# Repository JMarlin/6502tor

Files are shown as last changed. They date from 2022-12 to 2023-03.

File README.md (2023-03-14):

# 6502tor

This is the project page for the 6502tor project, a minimal educational computer designed to teach the fundamentals of how a computer actually operates near the lowest levels.

If you received an assembled rev1 board as a holiday gift, it probably looks something like this:

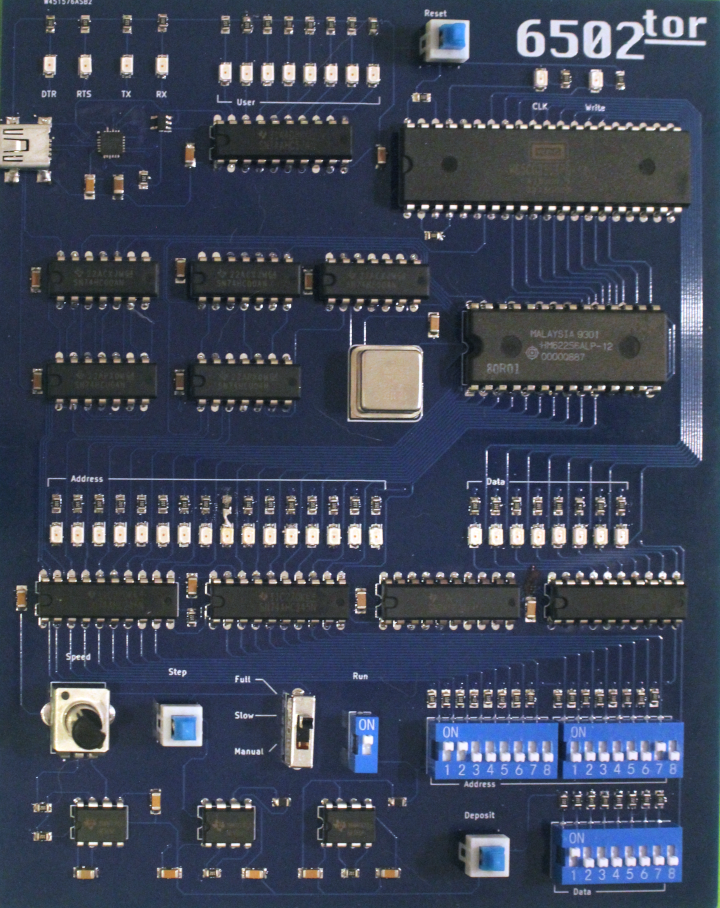
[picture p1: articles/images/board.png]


If you're interested in details about how the actual board is designed and built, you should check out the [hardware](hardware/README.md) section.

## Using The Hardware

This computer system is simultaneously incredibly simple while, by the token of complete open-endedness this implies, very complicated. With only a handful of controls, you can get the 6502tor to perform any function that can be done by *any other* computer.

For that reason, most of the system operation is going to be provided by a series of tutorial articles that will be published over time and which can be found below:

### Tutorials:
 - [0000 0001 - Overview and writing to memory](https://youtu.be/rqbeiZjz4c4)
 - [0000 0010 - Memory maps and binary](https://youtu.be/jSdUKUccR5Q)
 - [0000 0011 - Reset vector](https://youtu.be/KTeOp61t6co)
 - [0000 0100 - Executing your first instruction](https://youtu.be/9eZ2-8ygBwk)
 - [0000 0101 - Basic I/O](https://youtu.be/15wBBccO2ps)

### System Overview:

For the purpose of providing a quick reference so that you don't have to read through the articles if you need a reminder, the below chart provides a description of all the basic controls on the board:

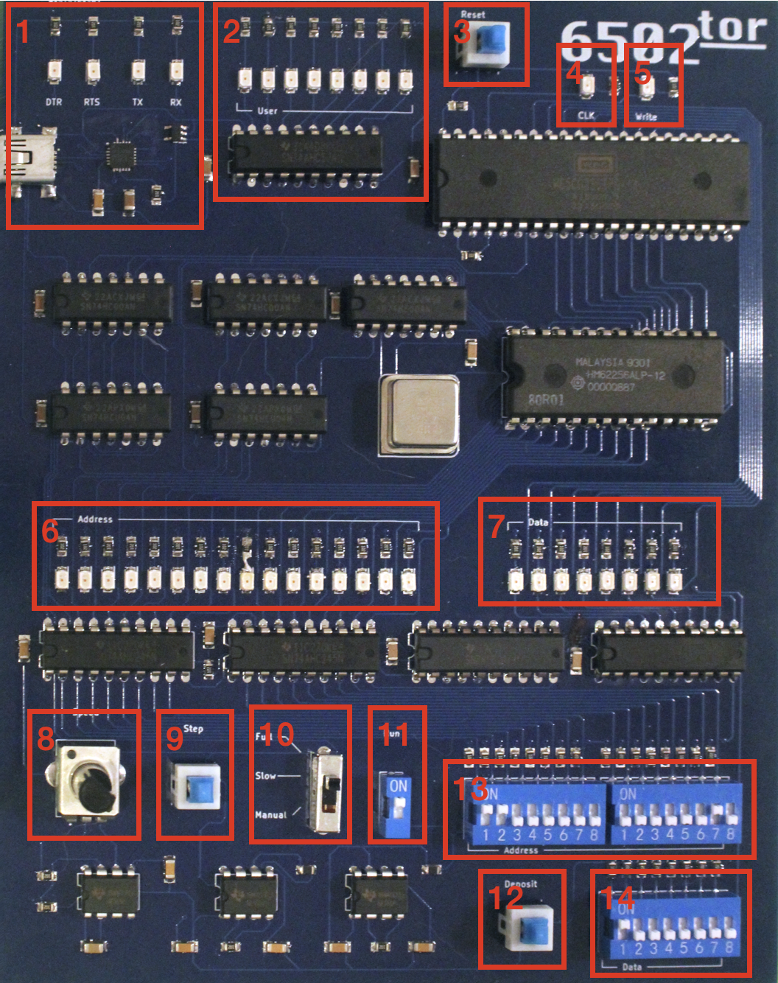
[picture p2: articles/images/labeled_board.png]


1. **USB Port** - Provides power to the system and also, in more advanced uses, serial communication with a host machine

2. **User Register** - Provides 8 bits of output and can be written to at any address between `0x4000` and `0xBFFF`. The top two bits are also attached to the USB chip for more advanced serial I/O purposes:
   - Bit 6: RXD
   - Bit 7: CTS

3. **CPU Reset** - A toggle switch that causes the CPU to do an internal reset when pressed in and allows the CPU to begin executing from the reset vector stored in RAM at `0xFFFC` when released. 
Should be pressed in for at least 3 clock cycles whenever the clock source is changed or in any other scenario where you want the CPU to begin running from its default state.

4. **CLK LED** - Displays the clock signal being fed into the CPU.

5. **Write LED** - Displays whether the system is currently reading or writing data from/to the bus. Probably backwards from what you expect, *there is a write occurring when this LED is **OFF***

6. **Address LEDs** - Display the address that is currently being driven on the address bus, whether that's by the CPU or by the `address switches` (depending on the run/program mode)

7. **Data LEDs** - Display the data that is currently being driven on the data bus, whether that's by the CPU or by the `data switches` (depending on the run/program mode). Note that in run mode, the data bus is only driven during the *high* portion of the clock cycle.

8. **Slow Clock Speed Control** - When the clock source switch is set to 'slow', controls the speed of the slow CPU clock (clockwise is faster).

9. **Step Button** - When the clock source switch is set to 'manual', directly controls the CPU clock. When pressed in, sets the `CLK` signal to low and when not pressed in sets the `CLK` signal to high.
It should be noted that data only appears on the data bus during the high portion of the clock cycle.

10. **Clock Source Switch** - Switches the CPU between three different clock sources/speed ranges:

     - **Full** - Connects the CPU directly to the 5 megahertz crystal oscillator (the metal can in the middle of the board)

     - **Slow** - Connects the CPU to a much slower RC oscillator that can run the CPU between ~0.5 hertz and a few kilohertz depending on how the `Slow Clock Speed Control` is set

     - **Manual** - Connects the clock directly to a debounced pushbutton so that you can manually step through clock cycles as slowly as you would like

11. **Run/Program Switch** - Switches the board between `run` mode, in which the CPU is controlling everything, and the `program` mode in which the CPU is disconnected from the bus and the data switches, address switches, and deposit button can be used to manually place instructions and data into RAM.

12. **Deposit Button** - When the run/program switch is in program mode, depressing this button causes the value set on the data switches to be written to the location specified by the address switches. *This is a toggle button, so make sure to press it twice for each deposit*.

13. **Address Switches** - When the run/program switch is in program mode, the value of these switches is displayed on the address LEDs and the value stored at that location is displayed on the data LEDs. If the deposit switch is pressed, the value on the data switches is written to the address set on these switches.

14. **Data Switches** - When the run/program switch is in program mode, the value on these switches is written to the location set on the address switches. When the run/program switch is in the run mode, the value of the lowest five data switches can be read at addresses from `0x4000` to `0x8FFF`. In this mode, the top three bits connect to the USB chip as follows:

    - Bit 5: TXD
    - Bit 6: RTS
    - Bit 7: DTR 

### Memory Map:
| **Start** | **End** | **Description** |
|---|---|---|
| 0x0000 | 0x3FFF  | 32K of RAM |
| 0x4000 | 0xBFFF  | Read data switches / Write user register |
| 0xC000 | 0xFFFF  | 32K of RAM |

## Reference Material And Resources
 - [6502 CPU datasheet](https://www.westerndesigncenter.com/wdc/documentation/w65c02s.pdf)
 - [6502 CPU instruction reference](https://www.masswerk.at/6502/6502_instruction_set.html)
 - [Online 6502 assembler](https://www.masswerk.at/6502/assembler.html) (for simple manual programming)
 - [cc65 compiler/cc65 assembler](https://github.com/cc65/cc65) (for more involved programming)
 - [RS232 serial communications on wikipedia](https://en.wikipedia.org/wiki/RS-232#Physical_interface)

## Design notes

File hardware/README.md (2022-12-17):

# Hardware

This directory contains the schematic and PCB project for the 6502tor hardware. The 6502tor board was designed in KiCAD, an EDA package that is free and open source. If you want to play with the CAD project, you can download KiCAD here:

 - [KiCAD Project Website](https://www.kicad.org/download/)

You can find the project in the `kicad` directory, but if you simply want to view the schematic you can find it in [the PDF in the same directory as this readme](6502tor_schematic.pdf)

## Caveats/Errata

Note that what is included here is the raw version of the project that was used to generate the first revision boards as shipped, and as such both include a handful of errors that are corrected on the shipped hardware with bodge wires:

 - Somehow KiCAD did not indicate to me that I managed to build two separate, unconnected ground nets. This can be fixed by making a connection between the ground pin (pin 10) on the user register IC (the 74574 next to the USB port) and the ground pin (pin 7) of any of the 7400 or 7404 chips in the glue logic section immediately below.

 - The order of the wires connecting the 74244 outputs back to the top three bits of the 74245 data tranceiver is reversed in the design from what it should be. This can be fixed by cutting the three traces that run just above the SMD capacitor located immediately to the left of the right-most 74245 (just above the DIP switches) and then connecting pins 2, 3, and 4 of that IC to pins 12, 14, and 16 of the adjacent 74244.

 - Bizarrely, there's absolutely no connection between the address bit 7 LED and its current-limiting resistor. The fix for this is to connect them.

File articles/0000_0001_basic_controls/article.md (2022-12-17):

-- **WIP** --
The basic system consists of a 6502 CPU, a 32-kilobyte RAM, an 8-bit 'user register' for output, and a set of toggle switches and buttons that are used to load code and data into memory, switch between data entry/run mode, and control the CPU execution speed.

This is modeled off of 'full size' computers (as opposed to microcomputers) of the 50s through 70s -- back when there weren't any very good ROM technologies and the machine would be bootstrapped by loading initial code into RAM via one of these 'blinkenlights front panels' -- for more info on their history, check out [this wiki article](https://en.wikipedia.org/wiki/Front_panel). 

The 6502tor is built around a 6502 CPU, a type of 8-bit CPU that's been in production since 1975 and was used in a number of notable machines throughout the 80s including the Apple II, Commodore 64, BBC Micro, and even the Nintendo Entertainment System and Atari 2600.

A CPU communicates with the outside world by loading and storing commands and data between other devices that are connected to it. This loading and storing is done using a pair of busses called the `address bus` and the `data bus` along with a set of `control signals` ('bus' is just a fancy word for a bunch of related wires). The address bus tells connected devices *where* data should be read or written from/to, the data bus carries the actual data itself, and finally the control signals tell the connected devices *when and how* to perform the transfer.

Devices that connect to the CPU

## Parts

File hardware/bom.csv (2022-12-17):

Source: | /Users/josephmarlin/Documents/KiCad/6.0/projects/6502tor/6502tor.kicad_sch
Date: | Wednesday, December 07, 2022 at 05:16:50 PM
Tool: | Eeschema (6.0.9-0)
Generator: | /Applications/KiCad/KiCad.app/Contents/SharedSupport/plugins/bom_csv_grouped_by_value.py
Component Count: | 158
Individual Components:
Item | Qty | Reference(s) | Value | LibPart | Footprint | Datasheet
 |  | C1 | 0.01uf | 6502tor-eagle-import:C-USC1206 | 6502tor:C1206
 |  | C2 | 1uf | 6502tor-eagle-import:C-USC1206 | 6502tor:C1206
 |  | C3 | 0.01uf | 6502tor-eagle-import:C-USC1206 | 6502tor:C1206
 |  | C4 | 0.1uf | 6502tor-eagle-import:C-USC1206 | 6502tor:C1206
 |  | C5 | 0.1uf | 6502tor-eagle-import:C-USC1206 | 6502tor:C1206
 |  | C6 | 0.01uf | 6502tor-eagle-import:C-USC1206 | 6502tor:C1206
 |  | C7 | 0.1uf | 6502tor-eagle-import:C-USC1206 | 6502tor:C1206
 |  | C8 | 4.7uf | 6502tor-eagle-import:C-USC1206 | 6502tor:C1206
 |  | C9 | 0.1uf | 6502tor-eagle-import:C-USC1206 | 6502tor:C1206
 |  | C10 | 0.1uf | 6502tor-eagle-import:C-USC1206 | 6502tor:C1206
 |  | C11 | 0.1uf | 6502tor-eagle-import:C-USC1206 | 6502tor:C1206
 |  | C12 | 0.1uf | 6502tor-eagle-import:C-USC1206 | 6502tor:C1206
 |  | C13 | 0.1uf | 6502tor-eagle-import:C-USC1206 | 6502tor:C1206
 |  | C14 | 0.1uf | 6502tor-eagle-import:C-USC1206 | 6502tor:C1206
 |  | C15 | 0.1uf | 6502tor-eagle-import:C-USC1206 | 6502tor:C1206
 |  | C16 | 0.1uf | 6502tor-eagle-import:C-USC1206 | 6502tor:C1206
 |  | C17 | 0.1uf | 6502tor-eagle-import:C-USC1206 | 6502tor:C1206
 |  | C18 | 0.1uf | 6502tor-eagle-import:C-USC1206 | 6502tor:C1206
 |  | C19 | 0.1uf | 6502tor-eagle-import:C-USC1206 | 6502tor:C1206
 |  | C20 | 0.1uf | 6502tor-eagle-import:C-USC1206 | 6502tor:C1206
 |  | IC1 | W65C02SP | 6502tor-eagle-import:W65C02SP | 6502tor:DIL40
 |  | IC2 | 74245N | 6502tor-eagle-import:74245N | 6502tor:DIL20
 |  | IC3 | 7400N | 6502tor-eagle-import:7400N | 6502tor:DIL14
 |  | IC4 | 7400N | 6502tor-eagle-import:7400N | 6502tor:DIL14
 |  | IC5 | 7400N | 6502tor-eagle-import:7400N | 6502tor:DIL14
 |  | IC6 | 555N | 6502tor-eagle-import:555N | 6502tor:DIL08
 |  | IC7 | 555N | 6502tor-eagle-import:555N | 6502tor:DIL08
 |  | IC8 | 7404N | 6502tor-eagle-import:7404N | 6502tor:DIL14
 |  | IC9 | 7404N | 6502tor-eagle-import:7404N | 6502tor:DIL14
 |  | IC10 | 555N | 6502tor-eagle-import:555N | 6502tor:DIL08
 |  | IC11 | 74245N | 6502tor-eagle-import:74245N | 6502tor:DIL20
 |  | IC12 | 74245N | 6502tor-eagle-import:74245N | 6502tor:DIL20
 |  | IC14 | 74244N | 6502tor-eagle-import:74244N | 6502tor:DIL20
 |  | IC15 | 74574N | 6502tor-eagle-import:74574N | 6502tor:DIL20
 |  | IC16 | CP2102N-A02-GQFN24 | 6502tor-eagle-import:CP2102N-A02-GQFN24 | 6502tor:QFN50P400X400X80-25N
 |  | IC17 | TPS7A2036PDBVR | 6502tor-eagle-import:TPS7A2036PDBVR | 6502tor:SOT95P280X145-5N
 |  | J1 | UJ2-MBH-1-SMT-TR | 6502tor-eagle-import:UJ2-MBH-1-SMT-TR | 6502tor:UJ2MBH1SMTTR
 |  | LED1 | CLM3C-AKW-CTBVA253 | 6502tor-eagle-import:CLM3C-AKW-CTBVA253 | 6502tor:LEDM3020X140N
 |  | LED2 | CLM3C-AKW-CTBVA253 | 6502tor-eagle-import:CLM3C-AKW-CTBVA253 | 6502tor:LEDM3020X140N
 |  | LED3 | CLM3C-AKW-CTBVA253 | 6502tor-eagle-import:CLM3C-AKW-CTBVA253 | 6502tor:LEDM3020X140N
 |  | LED4 | CLM3C-AKW-CTBVA253 | 6502tor-eagle-import:CLM3C-AKW-CTBVA253 | 6502tor:LEDM3020X140N
 |  | LED5 | CLM3C-AKW-CTBVA253 | 6502tor-eagle-import:CLM3C-AKW-CTBVA253 | 6502tor:LEDM3020X140N
 |  | LED6 | CLM3C-AKW-CTBVA253 | 6502tor-eagle-import:CLM3C-AKW-CTBVA253 | 6502tor:LEDM3020X140N
 |  | LED7 | CLM3C-AKW-CTBVA253 | 6502tor-eagle-import:CLM3C-AKW-CTBVA253 | 6502tor:LEDM3020X140N
 |  | LED8 | CLM3C-AKW-CTBVA253 | 6502tor-eagle-import:CLM3C-AKW-CTBVA253 | 6502tor:LEDM3020X140N
 |  | LED9 | CLM3C-AKW-CTBVA253 | 6502tor-eagle-import:CLM3C-AKW-CTBVA253 | 6502tor:LEDM3020X140N
 |  | LED10 | CLM3C-AKW-CTBVA253 | 6502tor-eagle-import:CLM3C-AKW-CTBVA253 | 6502tor:LEDM3020X140N
 |  | LED11 | CLM3C-AKW-CTBVA253 | 6502tor-eagle-import:CLM3C-AKW-CTBVA253 | 6502tor:LEDM3020X140N
 |  | LED12 | CLM3C-AKW-CTBVA253 | 6502tor-eagle-import:CLM3C-AKW-CTBVA253 | 6502tor:LEDM3020X140N
 |  | LED13 | CLM3C-AKW-CTBVA253 | 6502tor-eagle-import:CLM3C-AKW-CTBVA253 | 6502tor:LEDM3020X140N
 |  | LED14 | CLM3C-AKW-CTBVA253 | 6502tor-eagle-import:CLM3C-AKW-CTBVA253 | 6502tor:LEDM3020X140N
 |  | LED15 | CLM3C-AKW-CTBVA253 | 6502tor-eagle-import:CLM3C-AKW-CTBVA253 | 6502tor:LEDM3020X140N
 |  | LED16 | CLM3C-AKW-CTBVA253 | 6502tor-eagle-import:CLM3C-AKW-CTBVA253 | 6502tor:LEDM3020X140N
 |  | LED17 | CLM3C-AKW-CTBVA253 | 6502tor-eagle-import:CLM3C-AKW-CTBVA253 | 6502tor:LEDM3020X140N
 |  | LED18 | CLM3C-AKW-CTBVA253 | 6502tor-eagle-import:CLM3C-AKW-CTBVA253 | 6502tor:LEDM3020X140N
 |  | LED19 | CLM3C-AKW-CTBVA253 | 6502tor-eagle-import:CLM3C-AKW-CTBVA253 | 6502tor:LEDM3020X140N
 |  | LED20 | CLM3C-AKW-CTBVA253 | 6502tor-eagle-import:CLM3C-AKW-CTBVA253 | 6502tor:LEDM3020X140N
 |  | LED21 | CLM3C-AKW-CTBVA253 | 6502tor-eagle-import:CLM3C-AKW-CTBVA253 | 6502tor:LEDM3020X140N
 |  | LED22 | CLM3C-AKW-CTBVA253 | 6502tor-eagle-import:CLM3C-AKW-CTBVA253 | 6502tor:LEDM3020X140N
 |  | LED23 | CLM3C-AKW-CTBVA253 | 6502tor-eagle-import:CLM3C-AKW-CTBVA253 | 6502tor:LEDM3020X140N
 |  | LED24 | CLM3C-AKW-CTBVA253 | 6502tor-eagle-import:CLM3C-AKW-CTBVA253 | 6502tor:LEDM3020X140N
 |  | LED25 | CLM3C-AKW-CTBVA253 | 6502tor-eagle-import:CLM3C-AKW-CTBVA253 | 6502tor:LEDM3020X140N
 |  | LED26 | CLM3C-AKW-CTBVA253 | 6502tor-eagle-import:CLM3C-AKW-CTBVA253 | 6502tor:LEDM3020X140N
 |  | LED27 | CLM3C-AKW-CTBVA253 | 6502tor-eagle-import:CLM3C-AKW-CTBVA253 | 6502tor:LEDM3020X140N
 |  | LED28 | CLM3C-AKW-CTBVA253 | 6502tor-eagle-import:CLM3C-AKW-CTBVA253 | 6502tor:LEDM3020X140N
 |  | LED29 | CLM3C-AKW-CTBVA253 | 6502tor-eagle-import:CLM3C-AKW-CTBVA253 | 6502tor:LEDM3020X140N
 |  | LED30 | CLM3C-AKW-CTBVA253 | 6502tor-eagle-import:CLM3C-AKW-CTBVA253 | 6502tor:LEDM3020X140N
 |  | LED31 | CLM3C-AKW-CTBVA253 | 6502tor-eagle-import:CLM3C-AKW-CTBVA253 | 6502tor:LEDM3020X140N
 |  | LED32 | CLM3C-AKW-CTBVA253 | 6502tor-eagle-import:CLM3C-AKW-CTBVA253 | 6502tor:LEDM3020X140N
 |  | LED33 | CLM3C-AKW-CTBVA253 | 6502tor-eagle-import:CLM3C-AKW-CTBVA253 | 6502tor:LEDM3020X140N
 |  | LED34 | CLM3C-AKW-CTBVA253 | 6502tor-eagle-import:CLM3C-AKW-CTBVA253 | 6502tor:LEDM3020X140N
 |  | LED35 | CLM3C-AKW-CTBVA253 | 6502tor-eagle-import:CLM3C-AKW-CTBVA253 | 6502tor:LEDM3020X140N
 |  | LED36 | CLM3C-AKW-CTBVA253 | 6502tor-eagle-import:CLM3C-AKW-CTBVA253 | 6502tor:LEDM3020X140N
 |  | LED37 | CLM3C-AKW-CTBVA253 | 6502tor-eagle-import:CLM3C-AKW-CTBVA253 | 6502tor:LEDM3020X140N
 |  | LED38 | CLM3C-AKW-CTBVA253 | 6502tor-eagle-import:CLM3C-AKW-CTBVA253 | 6502tor:LEDM3020X140N
 |  | QG1 | QG5460 | 6502tor-eagle-import:QG5460 | 6502tor:DIL08S
 |  | R1 | R-US_R0805 | 6502tor-eagle-import:R-US_R0805 | 6502tor:R0805
 |  | R2 | R-US_R0805 | 6502tor-eagle-import:R-US_R0805 | 6502tor:R0805
 |  | R3 | R-US_R0805 | 6502tor-eagle-import:R-US_R0805 | 6502tor:R0805
 |  | R4 | R-US_R0805 | 6502tor-eagle-import:R-US_R0805 | 6502tor:R0805
 |  | R5 | R-US_R0805 | 6502tor-eagle-import:R-US_R0805 | 6502tor:R0805
 |  | R6 | R-US_R0805 | 6502tor-eagle-import:R-US_R0805 | 6502tor:R0805
 |  | R7 | R-US_R0805 | 6502tor-eagle-import:R-US_R0805 | 6502tor:R0805
 |  | R8 | R-US_R0805 | 6502tor-eagle-import:R-US_R0805 | 6502tor:R0805
 |  | R9 | R-US_R0805 | 6502tor-eagle-import:R-US_R0805 | 6502tor:R0805
 |  | R10 | R-US_R0805 | 6502tor-eagle-import:R-US_R0805 | 6502tor:R0805
 |  | R11 | R-US_R0805 | 6502tor-eagle-import:R-US_R0805 | 6502tor:R0805
 |  | R12 | R-US_R0805 | 6502tor-eagle-import:R-US_R0805 | 6502tor:R0805
 |  | R13 | R-US_R0805 | 6502tor-eagle-import:R-US_R0805 | 6502tor:R0805
 |  | R14 | R-US_R0805 | 6502tor-eagle-import:R-US_R0805 | 6502tor:R0805
 |  | R15 | R-US_R0805 | 6502tor-eagle-import:R-US_R0805 | 6502tor:R0805
 |  | R16 | R-US_R0805 | 6502tor-eagle-import:R-US_R0805 | 6502tor:R0805
 |  | R17 | R-US_R0805 | 6502tor-eagle-import:R-US_R0805 | 6502tor:R0805
 |  | R18 | R-US_R0805 | 6502tor-eagle-import:R-US_R0805 | 6502tor:R0805
 |  | R19 | R-US_R0805 | 6502tor-eagle-import:R-US_R0805 | 6502tor:R0805
 |  | R20 | R-US_R0805 | 6502tor-eagle-import:R-US_R0805 | 6502tor:R0805
 |  | R21 | R-US_R0805 | 6502tor-eagle-import:R-US_R0805 | 6502tor:R0805
 |  | R22 | R-US_R0805 | 6502tor-eagle-import:R-US_R0805 | 6502tor:R0805
 |  | R23 | R-US_R0805 | 6502tor-eagle-import:R-US_R0805 | 6502tor:R0805
 |  | R24 | R-US_R0805 | 6502tor-eagle-import:R-US_R0805 | 6502tor:R0805
 |  | R25 | R-US_R0805 | 6502tor-eagle-import:R-US_R0805 | 6502tor:R0805
 |  | R26 | R-US_R0805 | 6502tor-eagle-import:R-US_R0805 | 6502tor:R0805
 |  | R27 | R-US_R0805 | 6502tor-eagle-import:R-US_R0805 | 6502tor:R0805
 |  | R28 | R-US_R0805 | 6502tor-eagle-import:R-US_R0805 | 6502tor:R0805
 |  | R29 | R-US_R0805 | 6502tor-eagle-import:R-US_R0805 | 6502tor:R0805
 |  | R30 | R-US_R0805 | 6502tor-eagle-import:R-US_R0805 | 6502tor:R0805
 |  | R31 | R-US_R0805 | 6502tor-eagle-import:R-US_R0805 | 6502tor:R0805
 |  | R32 | R-US_R0805 | 6502tor-eagle-import:R-US_R0805 | 6502tor:R0805
 |  | R33 | R-US_R0805 | 6502tor-eagle-import:R-US_R0805 | 6502tor:R0805
 |  | R34 | R-US_R0805 | 6502tor-eagle-import:R-US_R0805 | 6502tor:R0805
 |  | R35 | R-US_R0805 | 6502tor-eagle-import:R-US_R0805 | 6502tor:R0805
 |  | R36 | R-US_R0805 | 6502tor-eagle-import:R-US_R0805 | 6502tor:R0805
 |  | R37 | R-US_R0805 | 6502tor-eagle-import:R-US_R0805 | 6502tor:R0805
 |  | R38 | R-US_R0805 | 6502tor-eagle-import:R-US_R0805 | 6502tor:R0805
 |  | R39 | R-US_R0805 | 6502tor-eagle-import:R-US_R0805 | 6502tor:R0805
 |  | R40 | R-US_R0805 | 6502tor-eagle-import:R-US_R0805 | 6502tor:R0805
 |  | R41 | R-US_R0805 | 6502tor-eagle-import:R-US_R0805 | 6502tor:R0805
 |  | R42 | R-US_R0805 | 6502tor-eagle-import:R-US_R0805 | 6502tor:R0805
 |  | R43 | R-US_R0805 | 6502tor-eagle-import:R-US_R0805 | 6502tor:R0805
 |  | R44 | R-US_R0805 | 6502tor-eagle-import:R-US_R0805 | 6502tor:R0805
 |  | R45 | R-US_R0805 | 6502tor-eagle-import:R-US_R0805 | 6502tor:R0805
 |  | R46 | R-US_R0805 | 6502tor-eagle-import:R-US_R0805 | 6502tor:R0805
 |  | R47 | R-US_R0805 | 6502tor-eagle-import:R-US_R0805 | 6502tor:R0805
 |  | R48 | R-US_R0805 | 6502tor-eagle-import:R-US_R0805 | 6502tor:R0805
 |  | R49 | R-US_R0805 | 6502tor-eagle-import:R-US_R0805 | 6502tor:R0805
 |  | R50 | R-US_R0805 | 6502tor-eagle-import:R-US_R0805 | 6502tor:R0805
 |  | R51 | R-US_R0805 | 6502tor-eagle-import:R-US_R0805 | 6502tor:R0805
 |  | R52 | R-US_R0805 | 6502tor-eagle-import:R-US_R0805 | 6502tor:R0805
 |  | R53 | R-US_R0805 | 6502tor-eagle-import:R-US_R0805 | 6502tor:R0805
 |  | R54 | R-US_R0805 | 6502tor-eagle-import:R-US_R0805 | 6502tor:R0805
 |  | R55 | R-US_R0805 | 6502tor-eagle-import:R-US_R0805 | 6502tor:R0805
 |  | R56 | R-US_R0805 | 6502tor-eagle-import:R-US_R0805 | 6502tor:R0805
 |  | R57 | R-US_R0805 | 6502tor-eagle-import:R-US_R0805 | 6502tor:R0805
 |  | R58 | R-US_R0805 | 6502tor-eagle-import:R-US_R0805 | 6502tor:R0805
 |  | R59 | R-US_R0805 | 6502tor-eagle-import:R-US_R0805 | 6502tor:R0805
 |  | R60 | PTV09A-4020F-B105 | 6502tor-eagle-import:PTV09A-4020F-B105 | 6502tor:PTV09A4020FB103
 |  | R61 | 1K | 6502tor-eagle-import:R-US_R0805 | 6502tor:R0805
 |  | R62 | 1K | 6502tor-eagle-import:R-US_R0805 | 6502tor:R0805
 |  | R63 | 1K | 6502tor-eagle-import:R-US_R0805 | 6502tor:R0805
 |  | R64 | 1M | 6502tor-eagle-import:R-US_R0805 | 6502tor:R0805
 |  | R65 | 1K | 6502tor-eagle-import:R-US_R0805 | 6502tor:R0805
 |  | R66 | 1M | 6502tor-eagle-import:R-US_R0805 | 6502tor:R0805
 |  | R67 | 1K | 6502tor-eagle-import:R-US_R0805 | 6502tor:R0805
 |  | R68 | R-US_R0805 | 6502tor-eagle-import:R-US_R0805 | 6502tor:R0805
 |  | R69 | R-US_R0805 | 6502tor-eagle-import:R-US_R0805 | 6502tor:R0805
 |  | R70 | 1K | 6502tor-eagle-import:R-US_R0805 | 6502tor:R0805
 |  | R71 | 1K | 6502tor-eagle-import:R-US_R0805 | 6502tor:R0805
 |  | R72 | 1K | 6502tor-eagle-import:R-US_R0805 | 6502tor:R0805
 |  | R73 | 1K | 6502tor-eagle-import:R-US_R0805 | 6502tor:R0805
 |  | S1 | MHPS2273 | 6502tor-eagle-import:MHPS2273 | 6502tor:MHPS2273
 |  | S3 | MHPS2273 | 6502tor-eagle-import:MHPS2273 | 6502tor:MHPS2273
 |  | S4 | OS103011MS8QP1 | 6502tor-eagle-import:OS103011MS8QP1 | 6502tor:OS103011MS8QP1
 |  | S5 | MHPS2273 | 6502tor-eagle-import:MHPS2273 | 6502tor:MHPS2273
 |  | SW1 | SW_DIP-8 | 6502tor-eagle-import:SW_DIP-8 | 6502tor:EDG-08
 |  | SW2 | SW_DIP-8 | 6502tor-eagle-import:SW_DIP-8 | 6502tor:EDG-08
 |  | SW3 | SW_DIP-8 | 6502tor-eagle-import:SW_DIP-8 | 6502tor:EDG-08
 |  | SW4 | SW_DIP-1 | 6502tor-eagle-import:SW_DIP-1 | 6502tor:EDG-01
 |  | U1 | HM62256BLP | Memory_RAM:HM62256BLP | Package_DIP:DIP-28_W15.24mm | https://web.mit.edu/6.115/www/document/62256.pdf
Collated Components:
Item | Qty | Reference(s) | Value | LibPart | Footprint | Datasheet
1 | 3 | C1, C3, C6 | 0.01uf | 6502tor-eagle-import:C-USC1206 | 6502tor:C1206
2 | 1 | C2 | 1uf | 6502tor-eagle-import:C-USC1206 | 6502tor:C1206
3 | 15 | C4, C5, C7, C9, C10, C11, C12, C13, C14, C15, C16, C17, C18, C19, C20 | 0.1uf | 6502tor-eagle-import:C-USC1206 | 6502tor:C1206
4 | 1 | C8 | 4.7uf | 6502tor-eagle-import:C-USC1206 | 6502tor:C1206
5 | 1 | IC1 | W65C02SP | 6502tor-eagle-import:W65C02SP | 6502tor:DIL40
6 | 3 | IC2, IC11, IC12 | 74245N | 6502tor-eagle-import:74245N | 6502tor:DIL20
7 | 3 | IC3, IC4, IC5 | 7400N | 6502tor-eagle-import:7400N | 6502tor:DIL14
8 | 3 | IC6, IC7, IC10 | 555N | 6502tor-eagle-import:555N | 6502tor:DIL08
9 | 2 | IC8, IC9 | 7404N | 6502tor-eagle-import:7404N | 6502tor:DIL14
10 | 1 | IC14 | 74244N | 6502tor-eagle-import:74244N | 6502tor:DIL20
11 | 1 | IC15 | 74574N | 6502tor-eagle-import:74574N | 6502tor:DIL20
12 | 1 | IC16 | CP2102N-A02-GQFN24 | 6502tor-eagle-import:CP2102N-A02-GQFN24 | 6502tor:QFN50P400X400X80-25N
13 | 1 | IC17 | TPS7A2036PDBVR | 6502tor-eagle-import:TPS7A2036PDBVR | 6502tor:SOT95P280X145-5N
14 | 1 | J1 | UJ2-MBH-1-SMT-TR | 6502tor-eagle-import:UJ2-MBH-1-SMT-TR | 6502tor:UJ2MBH1SMTTR
15 | 38 | LED1, LED2, LED3, LED4, LED5, LED6, LED7, LED8, LED9, LED10, LED11, LED12, LED13, LED14, LED15, LED16, LED17, LED18, LED19, LED20, LED21, LED22, LED23, LED24, LED25, LED26, LED27, LED28, LED29, LED30, LED31, LED32, LED33, LED34, LED35, LED36, LED37, LED38 | CLM3C-AKW-CTBVA253 | 6502tor-eagle-import:CLM3C-AKW-CTBVA253 | 6502tor:LEDM3020X140N
16 | 1 | QG1 | QG5460 | 6502tor-eagle-import:QG5460 | 6502tor:DIL08S
17 | 61 | R1, R2, R3, R4, R5, R6, R7, R8, R9, R10, R11, R12, R13, R14, R15, R16, R17, R18, R19, R20, R21, R22, R23, R24, R25, R26, R27, R28, R29, R30, R31, R32, R33, R34, R35, R36, R37, R38, R39, R40, R41, R42, R43, R44, R45, R46, R47, R48, R49, R50, R51, R52, R53, R54, R55, R56, R57, R58, R59, R68, R69 | R-US_R0805 | 6502tor-eagle-import:R-US_R0805 | 6502tor:R0805
18 | 1 | R60 | PTV09A-4020F-B105 | 6502tor-eagle-import:PTV09A-4020F-B105 | 6502tor:PTV09A4020FB103
19 | 9 | R61, R62, R63, R65, R67, R70, R71, R72, R73 | 1K | 6502tor-eagle-import:R-US_R0805 | 6502tor:R0805
20 | 2 | R64, R66 | 1M | 6502tor-eagle-import:R-US_R0805 | 6502tor:R0805
21 | 3 | S1, S3, S5 | MHPS2273 | 6502tor-eagle-import:MHPS2273 | 6502tor:MHPS2273
22 | 1 | S4 | OS103011MS8QP1 | 6502tor-eagle-import:OS103011MS8QP1 | 6502tor:OS103011MS8QP1
23 | 3 | SW1, SW2, SW3 | SW_DIP-8 | 6502tor-eagle-import:SW_DIP-8 | 6502tor:EDG-08
24 | 1 | SW4 | SW_DIP-1 | 6502tor-eagle-import:SW_DIP-1 | 6502tor:EDG-01
25 | 1 | U1 | HM62256BLP | Memory_RAM:HM62256BLP | Package_DIP:DIP-28_W15.24mm | https://web.mit.edu/6.115/www/document/62256.pdf

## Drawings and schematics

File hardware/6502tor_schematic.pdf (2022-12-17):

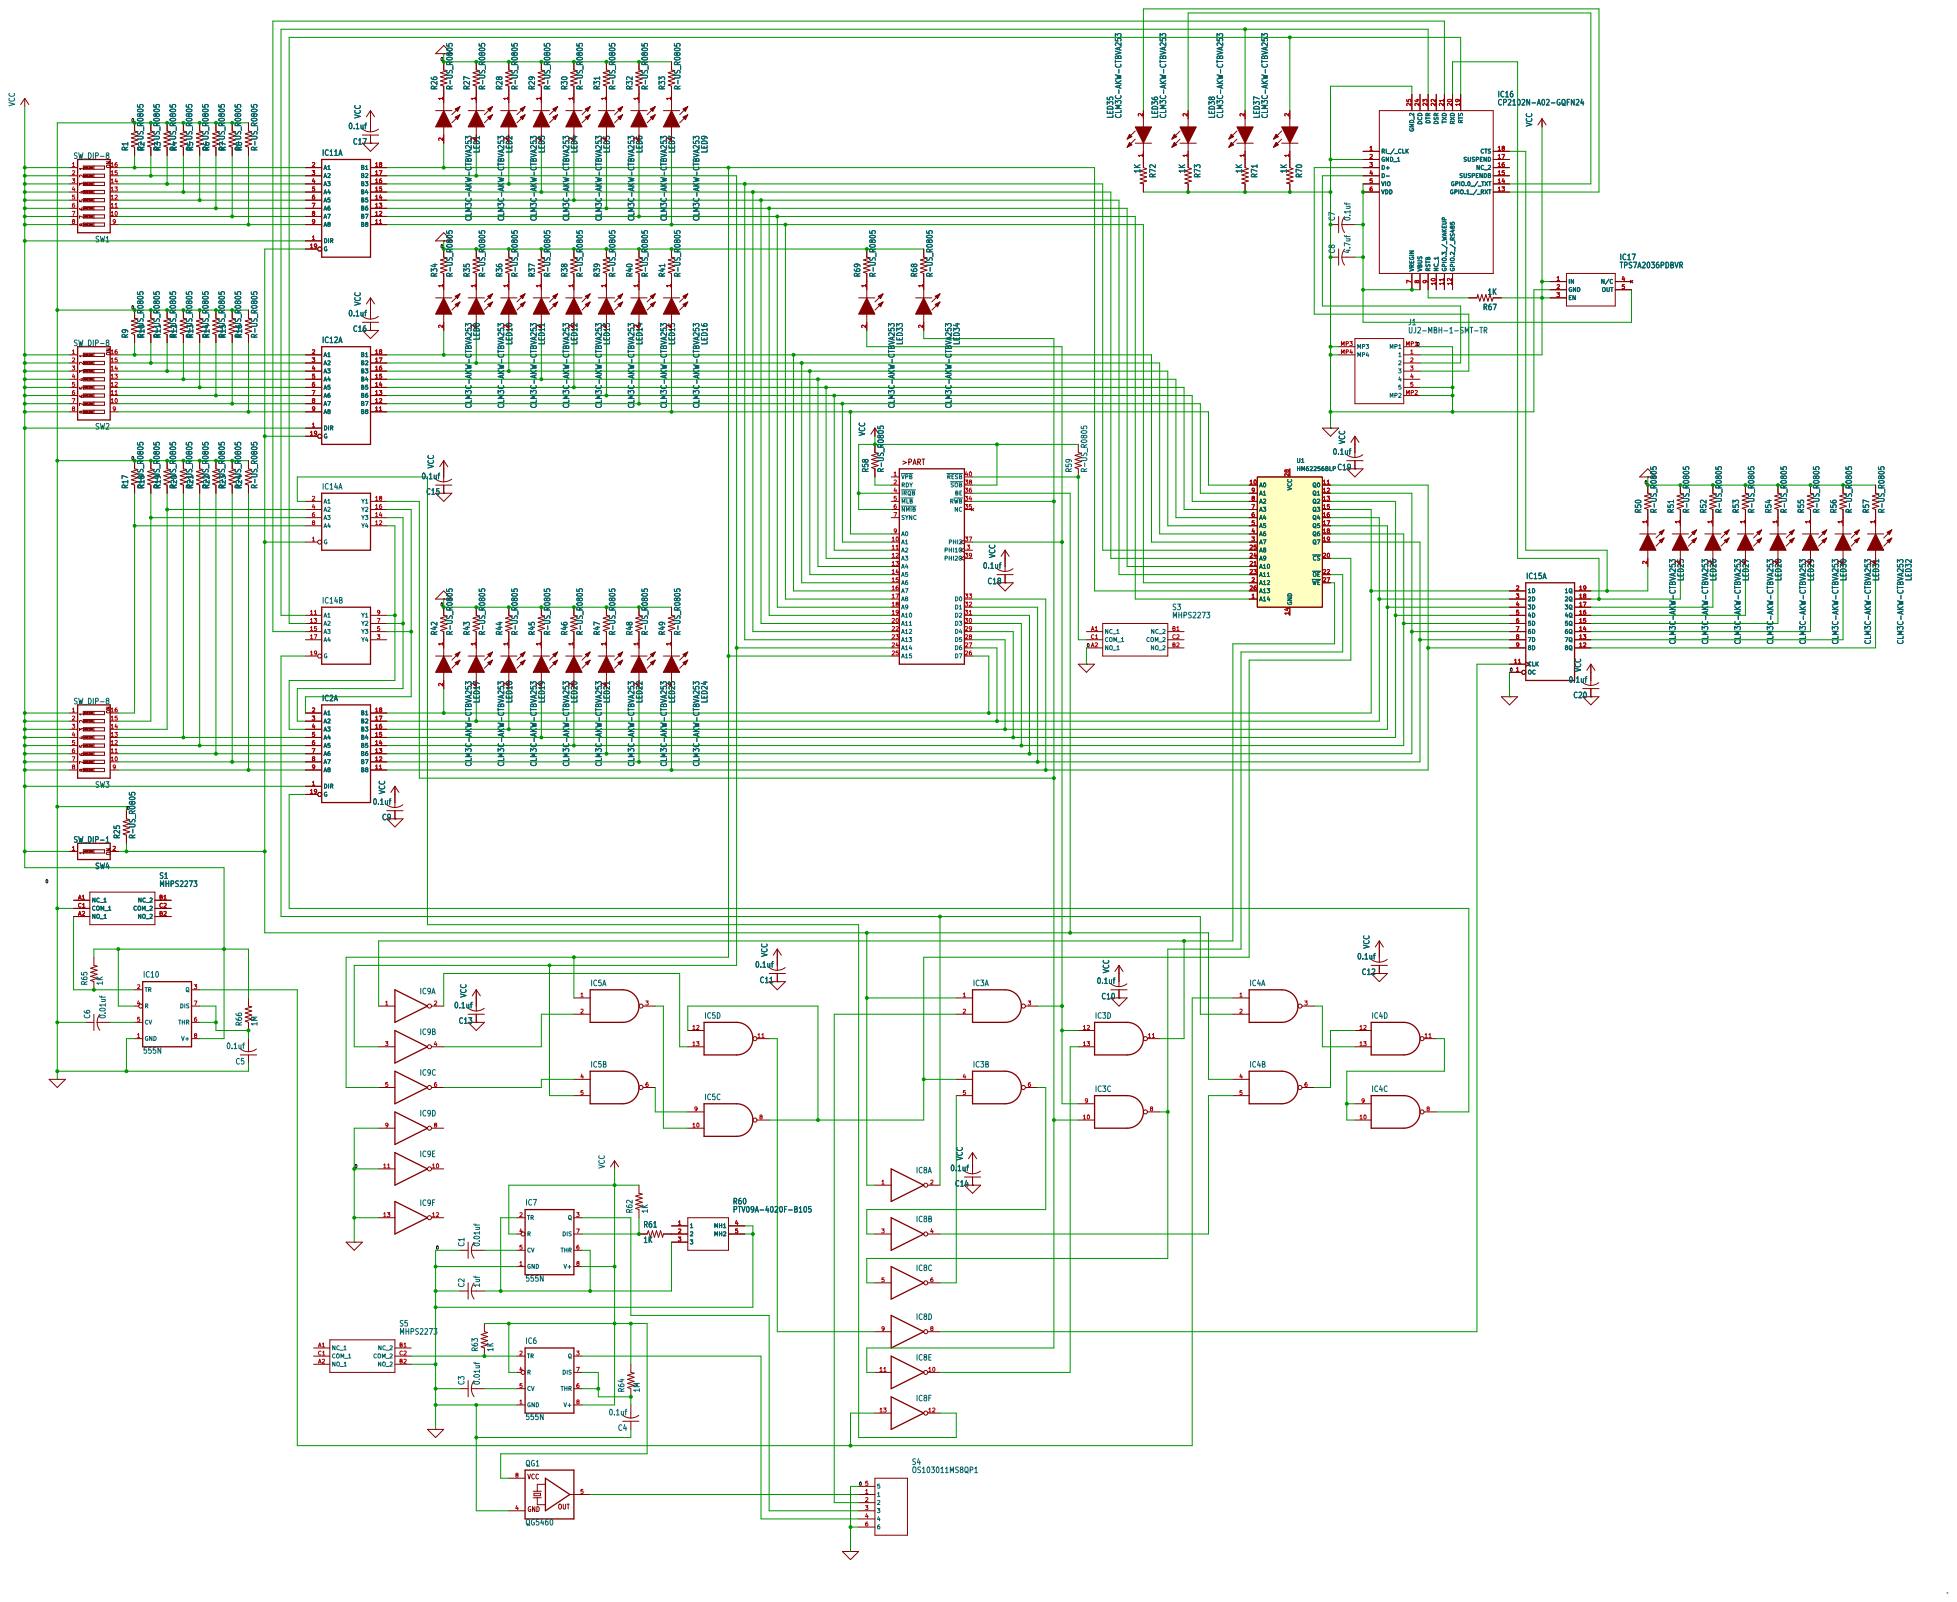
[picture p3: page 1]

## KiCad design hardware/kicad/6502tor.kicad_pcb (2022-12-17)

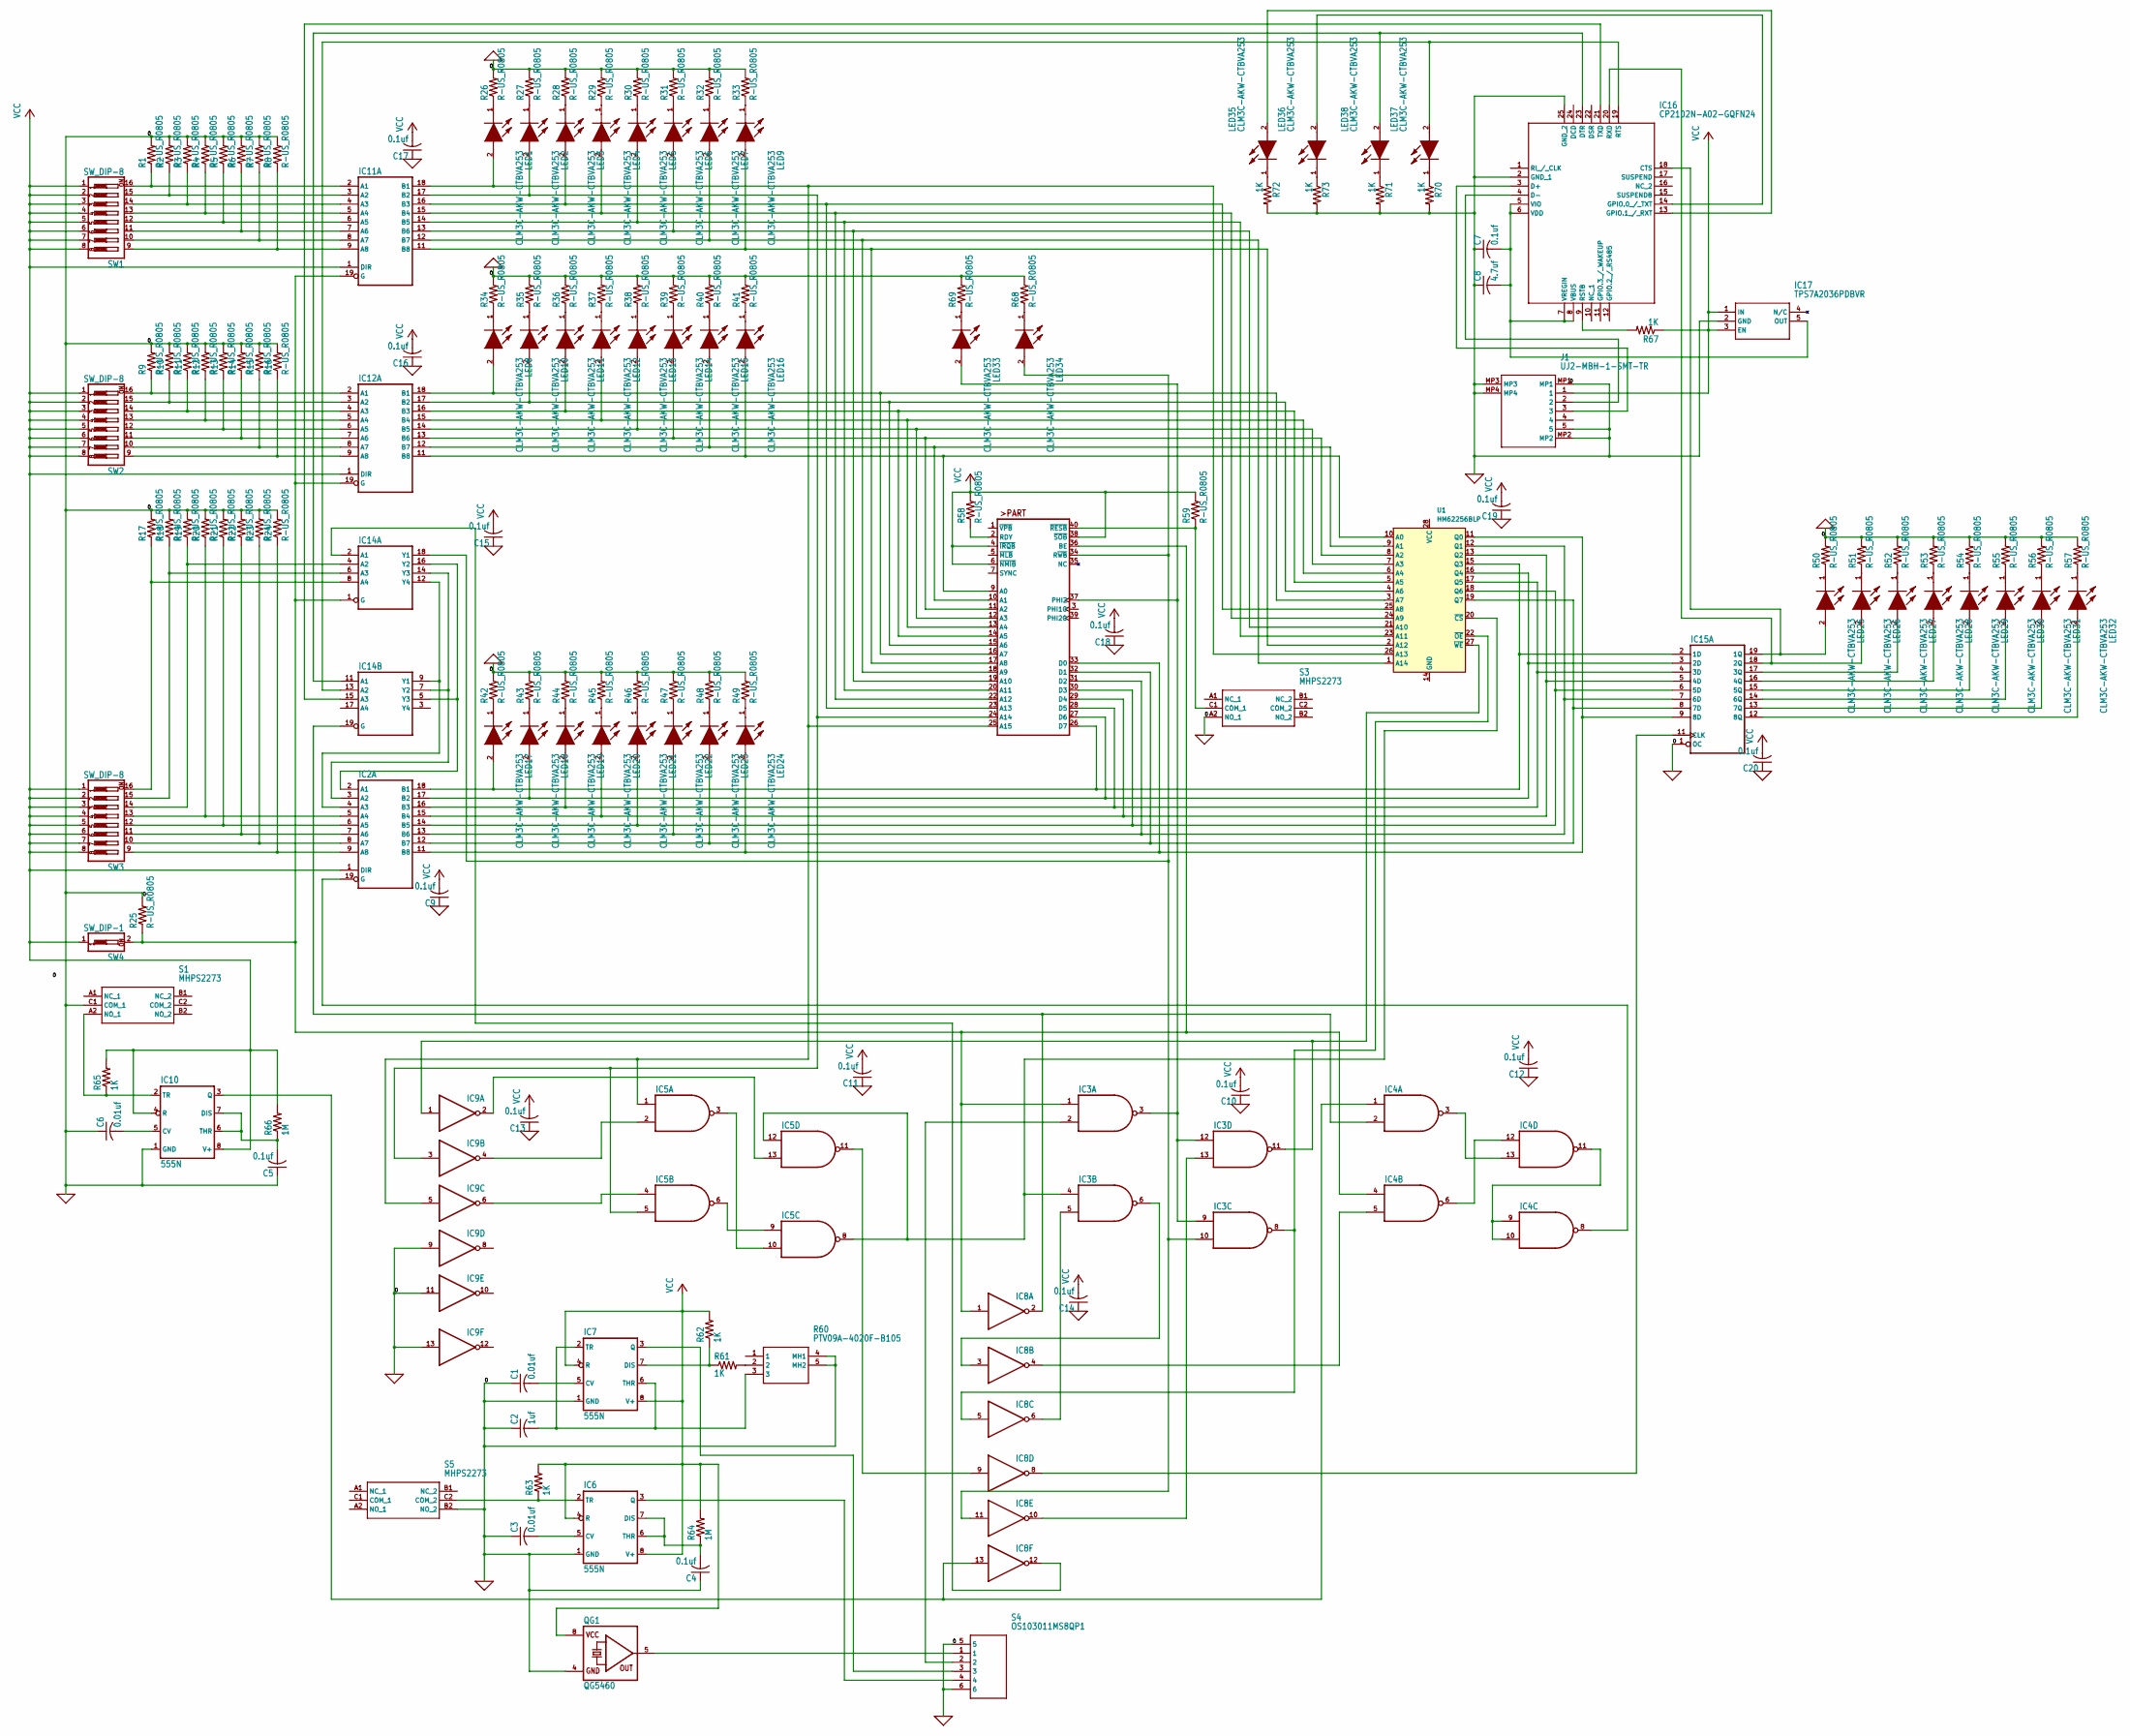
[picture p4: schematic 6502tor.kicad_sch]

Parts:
C1, C3, C6: 0.01uf; C1206
C2: 1uf; C1206
C4, C5, C7, C9, C10, C11, C12, C13, C14, C15, C16, C17, C18, C19, C20: 0.1uf; C1206
C8: 4.7uf; C1206
IC1: W65C02SP; DIL40
IC2, IC11, IC12: 74245N; DIL20
IC3, IC4, IC5: 7400N; DIL14
IC6, IC7, IC10: 555N; DIL08
IC8, IC9: 7404N; DIL14
IC14: 74244N; DIL20
IC15: 74574N; DIL20
IC16: CP2102N-A02-GQFN24; QFN50P400X400X80-25N
IC17: TPS7A2036PDBVR; SOT95P280X145-5N
J1: UJ2-MBH-1-SMT-TR; UJ2MBH1SMTTR
LED1, LED2, LED3, LED4, LED5, LED6, LED7, LED8, LED9, LED10, LED11, LED12, LED13, LED14, LED15, LED16, LED17, LED18, LED19, LED20, LED21, LED22, LED23, LED24, LED25, LED26, LED27, LED28, LED29, LED30, LED31, LED32, LED33, LED34, LED35, LED36, LED37, LED38: CLM3C-AKW-CTBVA253; LEDM3020X140N
QG1: QG5460; DIL08S
R1, R2, R3, R4, R5, R6, R7, R8, R9, R10, R11, R12, R13, R14, R15, R16, R17, R18, R19, R20, R21, R22, R23, R24, R25, R26, R27, R28, R29, R30, R31, R32, R33, R34, R35, R36, R37, R38, R39, R40, R41, R42, R43, R44, R45, R46, R47, R48, R49, R50, R51, R52, R53, R54, R55, R56, R57, R58, R59, R68, R69: R-US_R0805; R0805
R60: PTV09A-4020F-B105; PTV09A4020FB103
R61, R62, R63, R65, R67, R70, R71, R72, R73: 1K; R0805
R64, R66: 1M; R0805
S1, S3, S5: MHPS2273
S4: OS103011MS8QP1
SW1, SW2, SW3: SW_DIP-8; EDG-08
SW4: SW_DIP-1; EDG-01
U1: HM62256BLP; DIP-28_W15.24mm

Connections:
0: C1.1, C2.1, C3.1, C4.1, C5.1, C6.1, C7.1, C8.1, C9.1, C10.1, C11.1, C12.1, C13.1, C14.1, C15.1, C16.1, C17.1, C18.1, C19.1, C20.1, IC1.21 (VSS), IC2.10 (GND), IC3.7 (GND), IC4.7 (GND), IC5.7 (GND), IC6.1 (GND), IC7.1 (GND), IC8.7 (GND), IC9.7 (GND), IC9.9 (I), IC9.11 (I), IC9.13 (I), IC10.1 (GND), IC11.10 (GND), IC12.10 (GND), IC14.10 (GND), IC15.1 (OC), IC15.10 (GND), IC16.2 (GND_1), IC16.25 (GND_2), IC17.2 (GND), J1.5, J1.MP1, J1.MP2, J1.MP3, J1.MP4, QG1.4 (GND), R1.2, R2.2, R3.2, R4.2, R5.2, R6.2, R7.2, R8.2, R9.2, R10.2, R11.2, R12.2, R13.2, R14.2, R15.2, R16.2, R17.2, R18.2, R19.2, R20.2, R21.2, R22.2, R23.2, R24.2, R25.2, R26.2, R27.2, R28.2, R29.2, R30.2, R31.2, R32.2, R33.2, R34.2, R35.2, R36.2, R37.2, R38.2, R39.2, R40.2, R41.2, R42.2, R43.2, R44.2, R45.2, R46.2, R47.2, R48.2, R49.2, R50.2, R51.2, R52.2, R53.2, R54.2, R55.2, R56.2, R57.2, R60.4 (MH1), R60.5 (MH2), R68.2, R69.2, R70.2, R71.2, R72.2, R73.2, S1.C1 (COM_1), S3.A2 (NO_1), S4.5, S4.6, S5.B2 (NO_2), U1.14 (GND)
unnamed: C1.2, IC7.5 (CV)
unnamed: C2.2, IC7.2 (TR), IC7.6 (THR), R60.3
unnamed: C3.2, IC6.5 (CV)
unnamed: C4.2, IC6.6 (THR), IC6.7 (DIS), R64.1
unnamed: C5.2, IC10.6 (THR), IC10.7 (DIS), R66.1
unnamed: C6.2, IC10.5 (CV)
unnamed: C7.2, C8.2, IC16.5 (VIO), IC16.6 (VDD), IC16.7 (VREGIN), IC16.8 (VBUS), IC17.5 (OUT)
unnamed: IC1.2 (RDY), R58.1
unnamed: IC1.9 (A0), IC12.11 (B8), LED16.2 (A), U1.10 (A0)
unnamed: IC1.10 (A1), IC12.12 (B7), LED15.2 (A), U1.9 (A1)
unnamed: IC1.11 (A2), IC12.13 (B6), LED14.2 (A), U1.8 (A2)
unnamed: IC1.12 (A3), IC12.14 (B5), LED13.2 (A), U1.7 (A3)
unnamed: IC1.13 (A4), IC12.15 (B4), LED12.2 (A), U1.6 (A4)
unnamed: IC1.14 (A5), IC12.16 (B3), LED11.2 (A), U1.5 (A5)
unnamed: IC1.15 (A6), IC12.17 (B2), LED10.2 (A), U1.4 (A6)
unnamed: IC1.16 (A7), IC12.18 (B1), LED8.2 (A), U1.3 (A7)
unnamed: IC1.17 (A8), IC11.11 (B8), LED9.2 (A), U1.2 (A12)
unnamed: IC1.18 (A9), IC11.12 (B7), LED7.2 (A), U1.1 (A14)
unnamed: IC1.19 (A10), IC11.13 (B6), LED6.2 (A), U1.21 (A10)
unnamed: IC1.20 (A11), IC11.14 (B5), LED5.2 (A), U1.23 (A11)
unnamed: IC1.22 (A12), IC11.15 (B4), LED4.2 (A), U1.24 (A9)
unnamed: IC1.23 (A13), IC11.16 (B3), LED3.2 (A), U1.25 (A8)
unnamed: IC1.24 (A14), IC5.5 (I1), IC9.3 (I), IC11.17 (B2), LED2.2 (A)
unnamed: IC1.25 (A15), IC5.1 (I0), IC9.5 (I), IC11.18 (B1), LED1.2 (A), U1.26 (A13)
unnamed: IC1.26 (D7), IC2.18 (B1), IC15.2 (1D), LED17.2 (A), U1.15 (Q3)
unnamed: IC1.27 (D6), IC2.17 (B2), IC15.3 (2D), LED18.2 (A), U1.16 (Q4)
unnamed: IC1.28 (D5), IC2.16 (B3), IC15.4 (3D), LED19.2 (A), U1.17 (Q5)
unnamed: IC1.29 (D4), IC2.15 (B4), IC15.5 (4D), LED20.2 (A), U1.13 (Q2)
unnamed: IC1.30 (D3), IC2.14 (B5), IC15.6 (5D), LED21.2 (A), U1.18 (Q6)
unnamed: IC1.31 (D2), IC2.13 (B6), IC15.7 (6D), LED22.2 (A), U1.12 (Q1)
unnamed: IC1.32 (D1), IC2.12 (B7), IC15.8 (7D), LED23.2 (A), U1.19 (Q7)
unnamed: IC1.33 (D0), IC2.11 (B8), IC15.9 (8D), LED24.2 (A), U1.11 (Q0)
unnamed: IC1.34 (R~WB), IC3.10 (I1), IC8.11 (I), IC14.18 (Y1), LED34.2 (A)
unnamed: IC1.36 (BE), IC3.1 (I0), IC4.4 (I0), IC8.1 (I), IC11.19 (G), IC12.19 (G), IC14.1 (G), R25.1, SW4.2
unnamed: IC1.37 (PHI2), IC3.3 (O), IC3.9 (I0), IC3.12 (I0), LED33.2 (A)
unnamed: IC1.40 (~RESB), R59.1, S3.C1 (COM_1)
unnamed: IC3.2 (I1), S4.2
unnamed: IC3.4 (I0), IC5.8 (O), IC5.12 (I0), U1.20 (~CS)
unnamed: IC3.5 (I1), IC8.6 (O)
unnamed: IC3.6 (O), IC8.3 (I)
unnamed: IC3.8 (O), IC8.5 (I), U1.22 (~OE)
unnamed: IC3.11 (O), IC9.1 (I), U1.27 (~WE)
unnamed: IC3.13 (I1), IC8.10 (O)
unnamed: IC4.5 (I1), IC8.4 (O)
unnamed: IC2.19 (G), IC4.8 (O)
unnamed: IC4.9 (I0), IC4.10 (I1), IC4.11 (O)
unnamed: IC4.6 (O), IC4.12 (I0)
unnamed: IC4.3 (O), IC4.13 (I1)
unnamed: IC5.2 (I1), IC9.4 (O)
unnamed: IC5.4 (I0), IC9.6 (O)
unnamed: IC5.6 (O), IC5.9 (I0)
unnamed: IC5.3 (O), IC5.10 (I1)
unnamed: IC5.11 (O), IC8.9 (I)
unnamed: IC5.13 (I1), IC9.2 (O)
unnamed: IC6.2 (TR), R63.1, S5.C2 (COM_2)
unnamed: IC6.3 (Q), S4.4
unnamed: IC7.3 (Q), S4.3
unnamed: IC7.7 (DIS), R61.1, R62.1
unnamed: IC10.2 (TR), R65.1, S1.A2 (NO_1)
unnamed: IC4.1 (I0), IC8.13 (I), IC10.3 (Q)
unnamed: IC11.2 (A1), R1.1, SW1.16
unnamed: IC11.3 (A2), R2.1, SW1.15
unnamed: IC11.4 (A3), R3.1, SW1.14
unnamed: IC11.5 (A4), R4.1, SW1.13
unnamed: IC11.6 (A5), R5.1, SW1.12
unnamed: IC11.7 (A6), R6.1, SW1.11
unnamed: IC11.8 (A7), R7.1, SW1.10
unnamed: IC11.9 (A8), R8.1, SW1.9
unnamed: IC12.2 (A1), R9.1, SW2.16
unnamed: IC12.3 (A2), R10.1, SW2.15
unnamed: IC12.4 (A3), R11.1, SW2.14
unnamed: IC12.5 (A4), R12.1, SW2.13
unnamed: IC12.6 (A5), R13.1, SW2.12
unnamed: IC12.7 (A6), R14.1, SW2.11
unnamed: IC12.8 (A7), R15.1, SW2.10
unnamed: IC12.9 (A8), R16.1, SW2.9
unnamed: IC8.12 (O), IC14.2 (A1)
unnamed: IC14.4 (A2), R19.1, SW3.14
unnamed: IC14.6 (A3), R18.1, SW3.15
unnamed: IC14.8 (A4), R17.1, SW3.16
unnamed: IC14.11 (A1), IC16.23 (DTR), LED38.2 (A)
unnamed: IC2.4 (A3), IC14.9 (Y1), IC14.12 (Y4)
unnamed: IC14.13 (A2), IC16.19 (RTS), LED37.2 (A)
unnamed: IC2.3 (A2), IC14.7 (Y2), IC14.14 (Y3)
unnamed: IC14.15 (A3), IC16.21 (TXD)
unnamed: IC2.2 (A1), IC14.5 (Y3), IC14.16 (Y2)
unnamed: IC4.2 (I1), IC8.2 (O), IC14.19 (G)
unnamed: IC8.8 (O), IC15.11 (CLK)
unnamed: IC15.12 (8Q), LED32.2 (A)
unnamed: IC15.13 (7Q), LED31.2 (A)
unnamed: IC15.14 (6Q), LED30.2 (A)
unnamed: IC15.15 (5Q), LED29.2 (A)
unnamed: IC15.16 (4Q), LED28.2 (A)
unnamed: IC15.17 (3Q), LED27.2 (A)
unnamed: IC15.18 (2Q), IC16.20 (RXD), LED26.2 (A)
unnamed: IC15.19 (1Q), IC16.18 (CTS), LED25.2 (A)
unnamed: IC16.3 (D+), J1.3
unnamed: IC16.4 (D-), J1.2
unnamed: IC16.9 (RSTB), R67.2
unnamed: IC16.13 (GPIO.1_/_RXT), LED35.2 (A)
unnamed: IC16.14 (GPIO.0_/_TXT), LED36.2 (A)
unnamed: LED1.1 (K), R26.1
unnamed: LED2.1 (K), R27.1
unnamed: LED3.1 (K), R28.1
unnamed: LED4.1 (K), R29.1
unnamed: LED5.1 (K), R30.1
unnamed: LED6.1 (K), R31.1
unnamed: LED7.1 (K), R32.1
unnamed: LED8.1 (K), R34.1
unnamed: LED9.1 (K), R33.1
unnamed: LED10.1 (K), R35.1
unnamed: LED11.1 (K), R36.1
unnamed: LED12.1 (K), R37.1
unnamed: LED13.1 (K), R38.1
unnamed: LED14.1 (K), R39.1
unnamed: LED15.1 (K), R40.1
unnamed: LED16.1 (K), R41.1
unnamed: LED17.1 (K), R42.1
unnamed: LED18.1 (K), R43.1
unnamed: LED19.1 (K), R44.1
unnamed: LED20.1 (K), R45.1
unnamed: LED21.1 (K), R46.1
unnamed: LED22.1 (K), R47.1
unnamed: LED23.1 (K), R48.1
unnamed: LED24.1 (K), R49.1
unnamed: LED25.1 (K), R50.1
unnamed: LED26.1 (K), R51.1
unnamed: LED27.1 (K), R52.1
unnamed: LED28.1 (K), R53.1
unnamed: LED29.1 (K), R54.1
unnamed: LED30.1 (K), R55.1
unnamed: LED31.1 (K), R56.1
unnamed: LED32.1 (K), R57.1
unnamed: LED33.1 (K), R69.1
unnamed: LED34.1 (K), R68.1
unnamed: LED35.1 (K), R72.1
unnamed: LED36.1 (K), R73.1
unnamed: LED37.1 (K), R70.1
unnamed: LED38.1 (K), R71.1
unnamed: QG1.5 (OUT), S4.1
unnamed: IC2.5 (A4), R20.1, SW3.13
unnamed: IC2.6 (A5), R21.1, SW3.12
unnamed: IC2.7 (A6), R22.1, SW3.11
unnamed: IC2.8 (A7), R23.1, SW3.10
unnamed: IC2.9 (A8), R24.1, SW3.9
unnamed: R60.2, R61.2
VCC: C9.2, C10.2, C11.2, C12.2, C13.2, C14.2, C15.2, C16.2, C17.2, C18.2, C19.2, C20.2, IC1.4 (~IRQB), IC1.6 (~NMIB), IC1.8 (VDD), IC1.38 (~SOB), IC2.1 (DIR), IC2.20 (VCC), IC3.14 (VCC), IC4.14 (VCC), IC5.14 (VCC), IC6.4 (R), IC6.8 (V+), IC7.4 (R), IC7.8 (V+), IC8.14 (VCC), IC9.14 (VCC), IC10.4 (R), IC10.8 (V+), IC11.1 (DIR), IC11.20 (VCC), IC12.1 (DIR), IC12.20 (VCC), IC14.20 (VCC), IC15.20 (VCC), IC17.1 (IN), IC17.3 (EN), J1.1, QG1.8 (VCC), R58.2, R59.2, R62.2, R63.2, R64.2, R65.2, R66.2, R67.1, SW1.1, SW1.2, SW1.3, SW1.4, SW1.5, SW1.6, SW1.7, SW1.8, SW2.1, SW2.2, SW2.3, SW2.4, SW2.5, SW2.6, SW2.7, SW2.8, SW3.1, SW3.2, SW3.3, SW3.4, SW3.5, SW3.6, SW3.7, SW3.8, SW4.1, U1.28 (VCC)

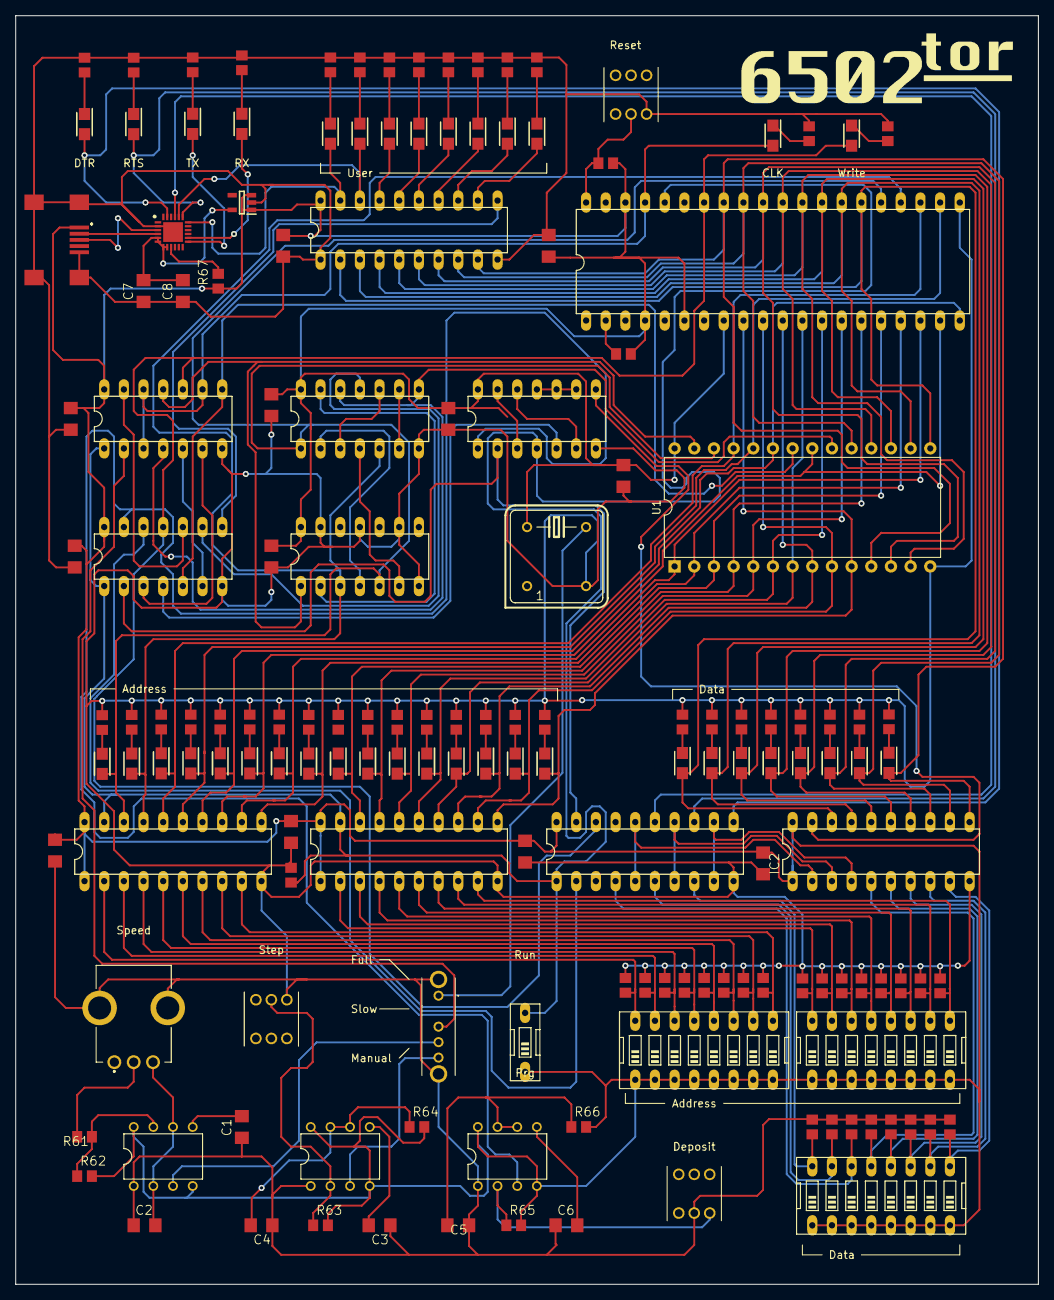
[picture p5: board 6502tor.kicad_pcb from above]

Board: 2 copper layers, 132.1 x 163.8 mm, 158 parts (0 on the bottom side), 148 nets.

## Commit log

2022-12-17 Initial main page and hardware section
    [6502tor-job.gbrjob, 6502tor.GBL, 6502tor.GBO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]
2022-12-21 Add tutor_butor source, remove .DS_Store
    [link.cfg]
